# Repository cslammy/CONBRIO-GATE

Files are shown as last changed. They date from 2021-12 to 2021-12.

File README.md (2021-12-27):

# CONBRIO-GATE
Synthesizer module that creates gates that speed up and slow down.
Please see the blog post here for more information:

https://audiodiwhy.blogspot.com/2021/12/con-brio-gate-boards-redesigned-to.html

This is a fix and redesign of the original project you can read about there.
https://audiodiwhy.blogspot.com/2019/04/conbrio-gate-generator-sounds-of-nature.html

Soundcloud demo for this module is here:
https://soundcloud.com/cslamm/con-brio-final

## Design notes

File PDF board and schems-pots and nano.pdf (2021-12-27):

GATEINLED | REVLED | OUTLED | GATEIN
a | FE

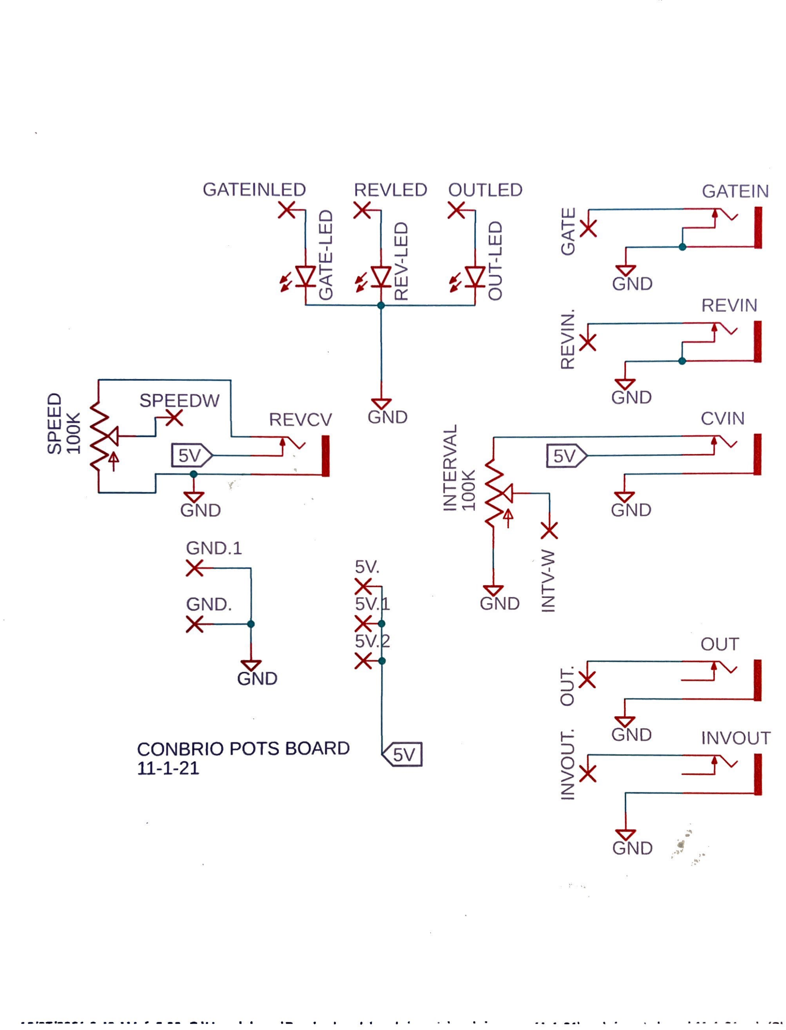
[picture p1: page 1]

<<
oI | O
5 | GND
° | . | REVIN
z
>
Lu
~
a | SPEEDW | GND
aa | <
a
Lu)
FO
ZO
GND.1 | | | 3s
| 5V. | | <
| | | ke
GND | 5V. | GND | Z
| BV.
GND | Ke | EN

Oo

KE | ND
CONBRIO POTS BOARD | 8g | o | NINVOUT 11-1-21 | Of | tC

za

*«
GND # .
c | o | r | o | n | e | n | e we meee eee | meee | se | = | . | . | es | oe | oa | aoe | -s | 8 | moe | ae | se | ee | wwe

## SPEED

## GATE-LED

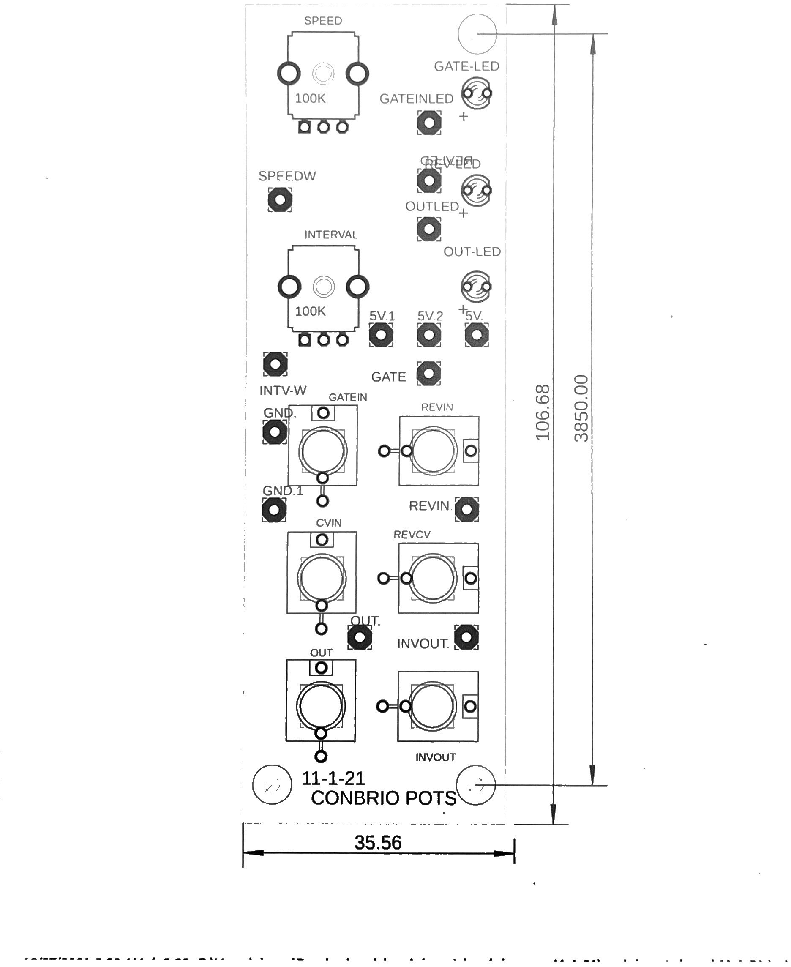
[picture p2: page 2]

# GATEINLED BB

O°

SPEEDW | O68
q
oO | ome
INTERVAL | o
| OUT-LED

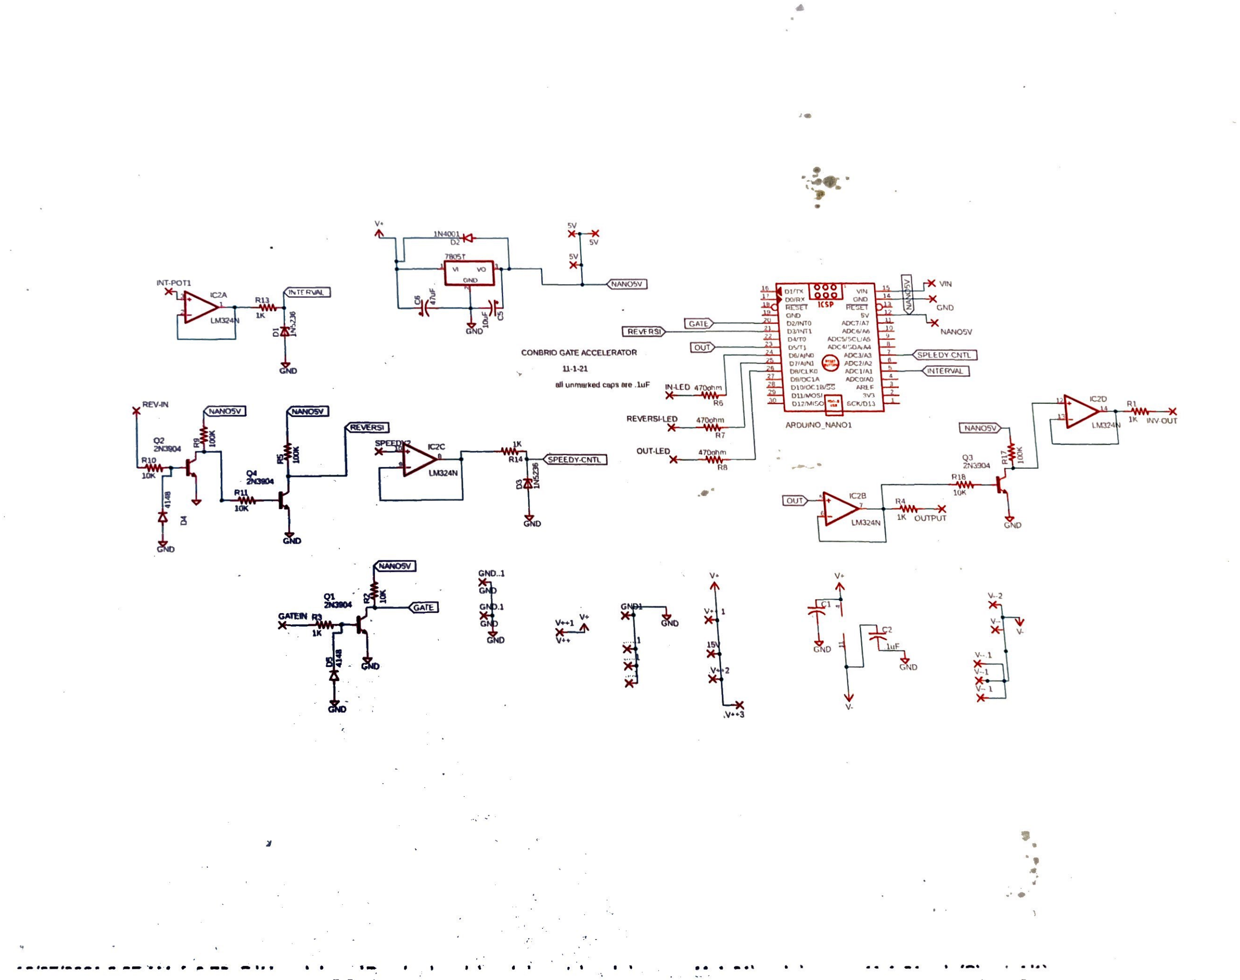
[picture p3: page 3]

so

CONBRIO GATE ACCELERATOR

2-222

oft unmarked caps are uF

¥

weed

7 | ~ | . | .
| | | 9 a ?

?@

? | y
« | -
?
ee | =
?
eetaminaans oom eee | o_o | me | ? | oe | eo | o8 | eos | oo | «wet | eo. | «2 | 2 we | + | ame | + | ates

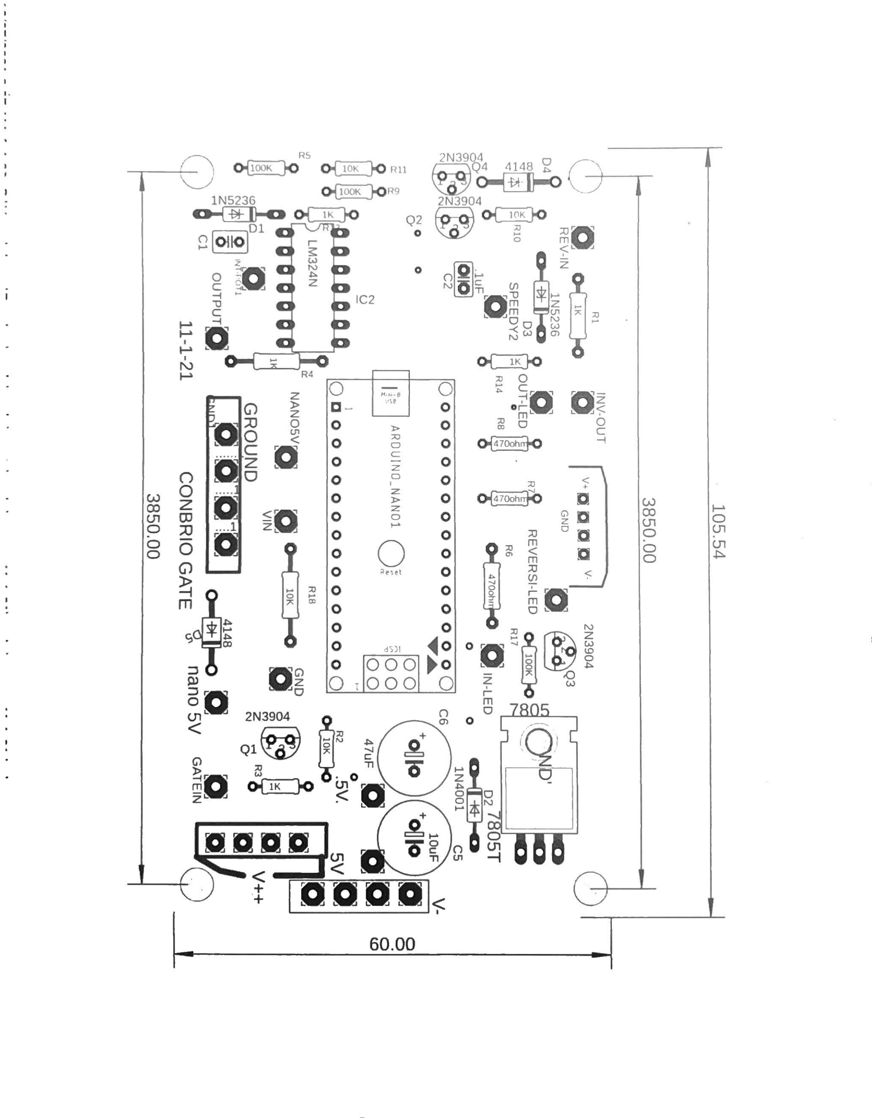
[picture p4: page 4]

105.54 ³⁸⁵⁰.00

Ve a oY²N3904

le el 032 | . RAE©

REVERS!- O00 }O2

# efrw 23] SPEEDY2 Bi?3 -

Ri?

Ar R14RB

230 4am) x{_4700hn] egINLED

## (110) aree 5

4a
c2 OCPCCO0C0D000000000C) cs

## Wa. ¹⁰uF

## -_?ollo 6°

Tszg;

A
47uF om

office a?BV.

4
wa

ourPuT

# Cyba7] 9

11-1-21 CONBRIOGATE nano *

5V_ GATEIN

ome

mee oo?.

v4 eotos eeoe toaa
wees

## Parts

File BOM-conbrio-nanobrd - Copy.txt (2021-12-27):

                                       
7805          7805T  7805T              TO220H       Positive VOLTAGE REGULATOR                                 
ARDUINO_NANO1        ARDUINO_NANO       ARDUINO_NANO Arduino Nano V3.0 Module                                   
C1            .1uF   C-US025-030X050    C025-030X050 CAPACITOR, American symbol                                 
C2            .1uF   C-US025-025X050    C025-025X050 CAPACITOR, American symbol                                 
C5            10uF   CPOL-USE3.5-10     E3,5-10      POLARIZED CAPACITOR, American symbol            C          
C6            47uF   CPOL-USE3.5-10     E3,5-10      POLARIZED CAPACITOR, American symbol            C          
D1            1N5236 ZENER-DIODEDO35Z10 DO35Z10      Z-Diode 5V                                                   
D2            1N4001 1N4148DO35-10      DO35-10      DIODE                                21                    
D3            1N5236 ZENER-DIODEDO35Z10 DO35Z10      Z-Diode 5V                                                   
D4            4148   1N4004             DO41-10      DIODE                                82                    
D5            4148   1N4004             DO41-10      DIODE                                82                    
               
IC2           LM324N LM324N             DIL14        OP AMP   

Note, for IC2, please do not use jfet opamp like TL084. LM324 or LM358 DIP IC is more reliable for this design.
                     
Q1            2N3904 2N3904             TO92         NPN Transistor                                             
Q2            2N3904 2N3904             TO92         NPN Transistor                                             
Q3            2N3904 2N3904             TO92         NPN Transistor                                             
Q4            2N3904 2N3904             TO92         NPN Transistor                                             
R1            1K     R-US_0207/10       0207/10      RESISTOR, American symbol                                  
R2            10K    R-US_0204/7        0204/7       RESISTOR, American symbol                                  
R3            1K     R-US_0204/7        0204/7       RESISTOR, American symbol                                  
R4            1K     R-US_0207/12       0207/12      RESISTOR, American symbol                                  
R5            100K   R-US_0204/7        0204/7       RESISTOR, American symbol                                  
R6            470ohm R-US_0207/10       0207/10      RESISTOR, American symbol                                  
R7            470ohm R-US_0204/7        0204/7       RESISTOR, American symbol                                  
R8            470ohm R-US_0204/7        0204/7       RESISTOR, American symbol                                  
R9            100K   R-US_0204/7        0204/7       RESISTOR, American symbol                                  
R10           10K    R-US_0204/7        0204/7       RESISTOR, American symbol                                  
R11           10K    R-US_0204/7        0204/7       RESISTOR, American symbol                                  
R13           1K     R-US_0204/7        0204/7       RESISTOR, American symbol                                  
R14           1K     R-US_0204/7        0204/7       RESISTOR, American symbol                                  
R17           100K   R-US_0204/7        0204/7       RESISTOR, American symbol                                  
R18           10K    R-US_0207/12       0207/12      RESISTOR, American symbol

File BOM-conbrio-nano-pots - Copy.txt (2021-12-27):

BOM-conbrio-nano-pots  for 11-1-21 design       

CVIN      THONKICONNNEW THONKICONNNEW    WQP-PJ301M-12_JACK 3.5mm socket for Eurorack modular synths                    
INVOUT    THONKICONNNEW THONKICONNNEW    WQP-PJ301M-12_JACK 3.5mm socket for Eurorack modular synths                    
OUT       THONKICONNNEW THONKICONNNEW    WQP-PJ301M-12_JACK 3.5mm socket for Eurorack modular synths 
GATEIN    THONKICONNNEW THONKICONNNEW    WQP-PJ301M-12_JACK 3.5mm socket for Eurorack modular synths      
REVCV     THONKICONNNEW THONKICONNNEW    WQP-PJ301M-12_JACK 3.5mm socket for Eurorack modular synths                    
REVIN     THONKICONNNEW THONKICONNNEW    WQP-PJ301M-12_JACK 3.5mm socket for Eurorack modular synths   
GATE-LED                LED3MM           LED3MM             LED                                               97        
OUT-LED                 LED3MM           LED3MM             LED                                               97        
REV-LED                 LED3MM           LED3MM             LED                                               97                
SPEED     100K          9MM_SNAP-IN_POT_ 9MM_SNAP-IN_POT    9mm vertical snap-in pot, Alpha / Panasonic style      
INTERVAL  100K          9MM_SNAP-IN_POT_ 9MM_SNAP-IN_POT    9mm vertical snap-in pot, Alpha / Panasonic style

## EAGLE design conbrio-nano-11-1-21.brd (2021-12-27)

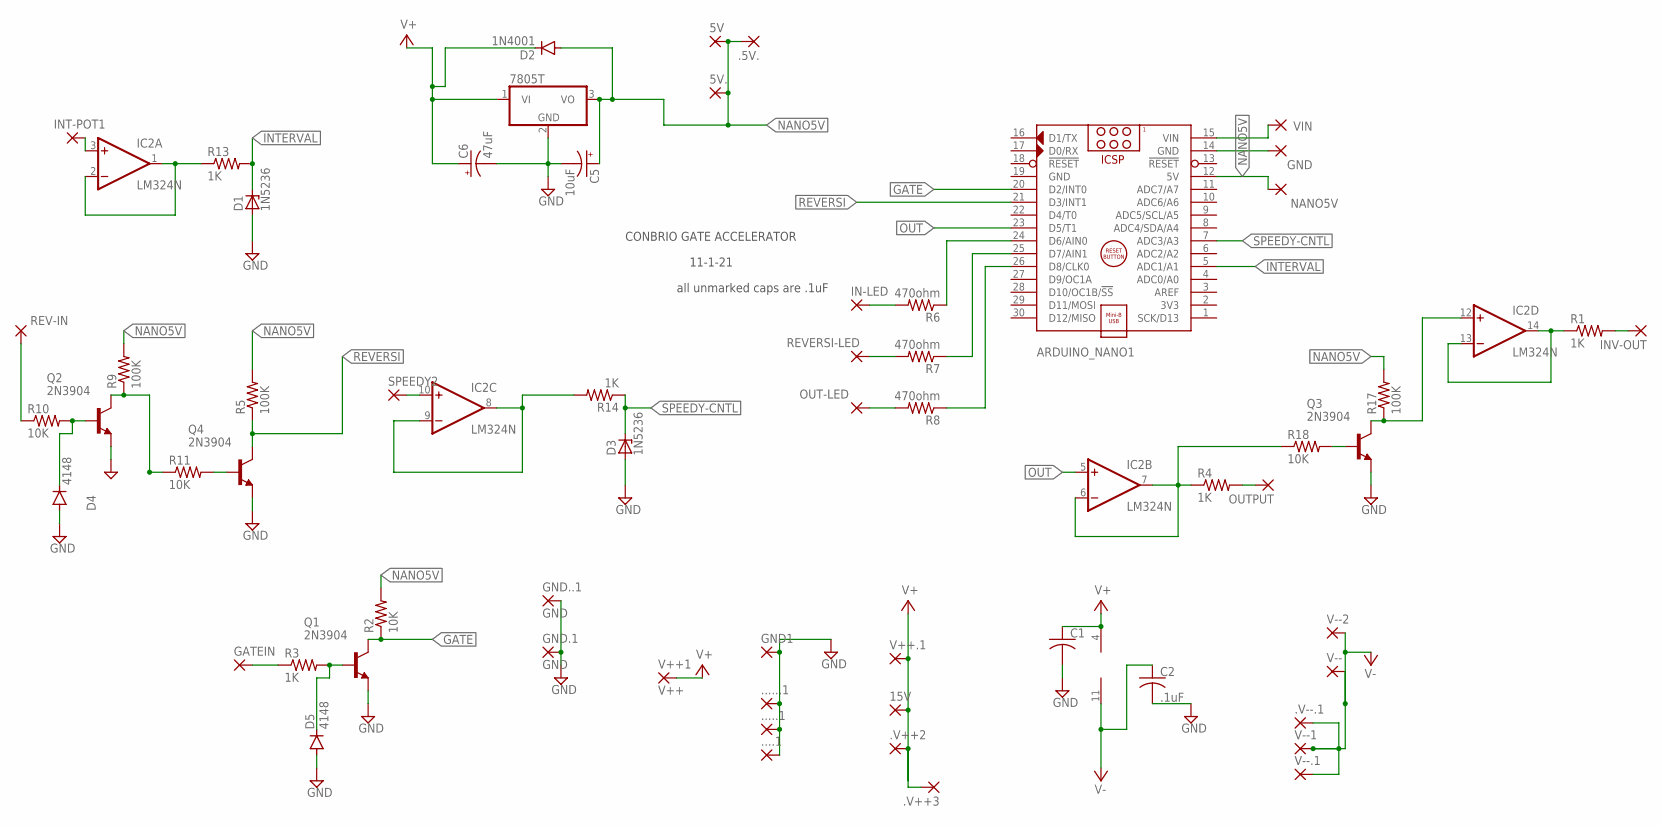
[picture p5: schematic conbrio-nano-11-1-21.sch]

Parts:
5V, .5V.: WIREPAD3,17/1,3; 3,17/1,3
5V.: WIREPAD3,17/1,2; 3,17/1,2
15V, .V++2, .V++3: 2,54/1,0
7805: 7805T; TO220H
....1, .....1, ......1, .V--.1: 3,17/1,3
ARDUINO_NANO1: ARDUINO_NANO
C1: C-US025-030X050; C025-030X050
C2: .1uF; C025-025X050
C5: 10uF; E3,5-10
C6: 47uF; E3,5-10
D1, D3: 1N5236; DO35Z10
D2: 1N4001; DO35-10
D4, D5: 4148; DO41-10
GATEIN: 3,17/1,3
GND, GND1: 3,17/1,3
GND.1, GND..1: GND; 1,6/0,8
IC2: LM324N; DIL14
IN-LED: 3,17/1,3
INT-POT1: 3,17/1,3
INV-OUT: 3,17/1,3
NANO5V: 3,17/1,3
OUT-LED: 3,17/1,3
OUTPUT: 3,17/1,3
Q1, Q2, Q3, Q4: 2N3904; TO92
R1: 1K; 0207/10
R2, R10, R11: 10K; 0204/7
R3, R13, R14: 1K; 0204/7
R4: 1K; 0207/12
R5, R9, R17: 100K; 0204/7
R6: 470ohm; 0207/10
R7, R8: 470ohm; 0204/7
R18: 10K; 0207/12
REV-IN: 3,17/1,3
REVERSI-LED: 3,17/1,3
SPEEDY2: 3,17/1,3
V++1: V++; 1,6/0,8
V++.1: 2,54/1,0
V--: WIREPAD3,17/1,1; 3,17/1,1
V--1, V--.1: 3,17/1,3
V--2: WIREPAD1,6/0,8; 1,6/0,8
VIN: 3,17/1,3

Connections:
GATE: ARDUINO_NANO1.20 (D2/INT0), Q1.1 (C), R2.1
GND: 7805.2 (GND), ....1.1, .....1.1, ......1.1, ARDUINO_NANO1.19 (GND), C1.2, C2.2, C5.-, C6.-, D1.A, D3.A, D4.A, D5.A, GND1.1, GND.1.1, GND..1.1, Q1.3 (E), Q2.3 (E), Q3.3 (E), Q4.3 (E)
INTERVAL: ARDUINO_NANO1.5 (ADC1/A1), D1.C, R13.2
INVOUT: IC2.13 (-IN), IC2.14 (OUT), R1.1
unnamed: GATEIN.1, R3.1
unnamed: D5.C, Q1.2 (B), R3.2
unnamed: INV-OUT.1, R1.2
unnamed: Q2.1 (C), R9.1, R11.1
unnamed: OUTPUT.1, R4.2
unnamed: IC2.3 (+IN), INT-POT1.1
unnamed: Q4.2 (B), R11.2
unnamed: IC2.6 (-IN), IC2.7 (OUT), R4.1, R18.1
unnamed: R10.1, REV-IN.1
unnamed: IN-LED.1, R6.2
unnamed: ARDUINO_NANO1.24 (D6/AIN0), R6.1
unnamed: R7.2, REVERSI-LED.1
unnamed: ARDUINO_NANO1.25 (D7/AIN1), R7.1
unnamed: OUT-LED.1, R8.2
unnamed: ARDUINO_NANO1.26 (D8/CLK0), R8.1
unnamed: IC2.12 (+IN), Q3.1 (C), R17.1
unnamed: IC2.10 (+IN), SPEEDY2.1
unnamed: D4.C, Q2.2 (B), R10.2
unnamed: IC2.1 (OUT), IC2.2 (-IN), R13.1
unnamed: Q3.2 (B), R18.2
unnamed: ARDUINO_NANO1.15 (VIN), VIN.1
unnamed: ARDUINO_NANO1.14 (GND), GND.1
NANO5V: 5V.1, 5V..1, 7805.3 (VO), .5V..1, ARDUINO_NANO1.12 (5V), C5.+, D2.A, NANO5V.1, R2.2, R5.2, R9.2, R17.2
OUT: ARDUINO_NANO1.23 (D5/T1), IC2.5 (+IN)
REVERSI: ARDUINO_NANO1.21 (D3/INT1), Q4.1 (C), R5.1
SPEEDY: IC2.8 (OUT), IC2.9 (-IN), R14.2
SPEEDY-CNTL: ARDUINO_NANO1.7 (ADC3/A3), D3.C, R14.1
V+: 15V.1, 7805.1 (VI), .V++2.1, .V++3.1, C1.1, C6.+, D2.C, IC2.4 (V+), V++1.1, V++.1.1
V-: .V--.1.1, C2.1, IC2.11 (V-), V--.1, V--1.1, V--2.1, V--.1.1

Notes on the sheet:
CONBRIO GATE ACCELERATOR
11-1-21
all unmarked caps are .1uF

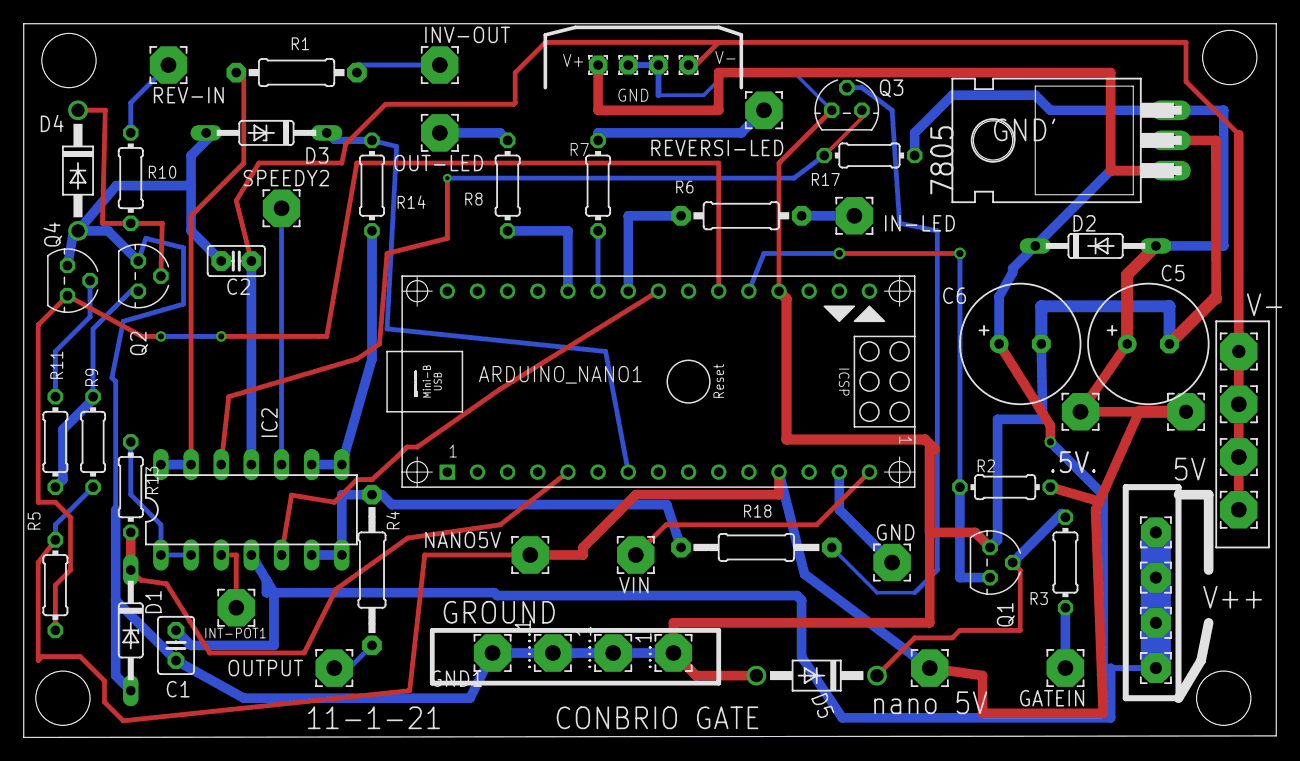
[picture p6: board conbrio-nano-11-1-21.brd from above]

Board: 2 copper layers, 105.5 x 60.1 mm, 62 parts (0 on the bottom side), 33 nets.

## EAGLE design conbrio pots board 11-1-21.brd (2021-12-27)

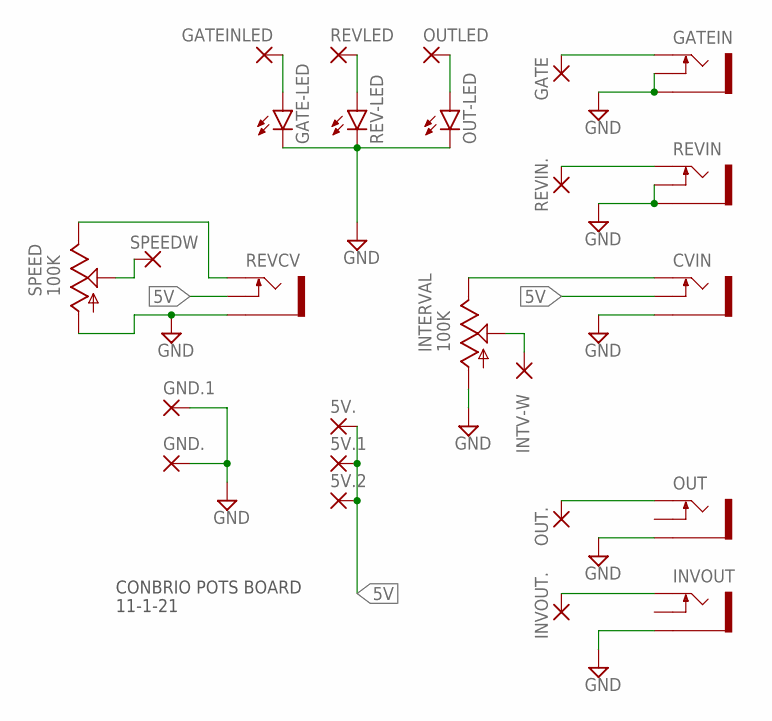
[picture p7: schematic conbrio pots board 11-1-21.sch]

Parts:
5V., 5V.1, 5V.2: WIREPAD3,17/1,3; 3,17/1,3
CVIN: THONKICONNNEW; WQP-PJ301M-12_JACK
GATE: WIREPAD3,17/1,3; 3,17/1,3
GATE-LED: LED3MM
GATEIN: THONKICONNNEW; WQP-PJ301M-12_JACK
GATEINLED: WIREPAD3,17/1,3; 3,17/1,3
GND., GND.1: WIREPAD3,17/1,3; 3,17/1,3
INTERVAL: 100K; 9MM_SNAP-IN_POT
INTV-W: WIREPAD3,17/1,3; 3,17/1,3
INVOUT: THONKICONNNEW; WQP-PJ301M-12_JACK
INVOUT.: WIREPAD3,17/1,3; 3,17/1,3
OUT: THONKICONNNEW; WQP-PJ301M-12_JACK
OUT-LED: LED3MM
OUT.: WIREPAD3,17/1,3; 3,17/1,3
OUTLED: WIREPAD3,17/1,3; 3,17/1,3
REV-LED: LED3MM
REVCV: THONKICONNNEW; WQP-PJ301M-12_JACK
REVIN: THONKICONNNEW; WQP-PJ301M-12_JACK
REVIN.: WIREPAD3,17/1,3; 3,17/1,3
REVLED: WIREPAD3,17/1,3; 3,17/1,3
SPEED: 100K; 9MM_SNAP-IN_POT
SPEEDW: WIREPAD3,17/1,3; 3,17/1,3

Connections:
5V: 5V..1, 5V.1.1, 5V.2.1, CVIN.P$2_SWITCH (SWITCH), REVCV.P$2_SWITCH (SWITCH)
GND: CVIN.P$3_SLEEVE (SLEEVE), GATE-LED.K (C), GATEIN.P$2_SWITCH (SWITCH), GATEIN.P$3_SLEEVE (SLEEVE), GND..1, GND.1.1, INTERVAL.1 (A), INVOUT.P$3_SLEEVE (SLEEVE), OUT.P$3_SLEEVE (SLEEVE), OUT-LED.K (C), REV-LED.K (C), REVCV.P$3_SLEEVE (SLEEVE), REVIN.P$2_SWITCH (SWITCH), REVIN.P$3_SLEEVE (SLEEVE), SPEED.1 (A)
unnamed: GATE-LED.A, GATEINLED.1
unnamed: REV-LED.A, REVLED.1
unnamed: OUT-LED.A, OUTLED.1
unnamed: CVIN.P$1_TIP (TIP), INTERVAL.3 (E)
unnamed: INTERVAL.2 (S), INTV-W.1
unnamed: REVCV.P$1_TIP (TIP), SPEED.3 (E)
unnamed: SPEED.2 (S), SPEEDW.1
unnamed: GATE.1, GATEIN.P$1_TIP (TIP)
unnamed: REVIN.P$1_TIP (TIP), REVIN..1
unnamed: OUT.P$1_TIP (TIP), OUT..1
unnamed: INVOUT.P$1_TIP (TIP), INVOUT..1

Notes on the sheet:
CONBRIO POTS BOARD
11-1-21

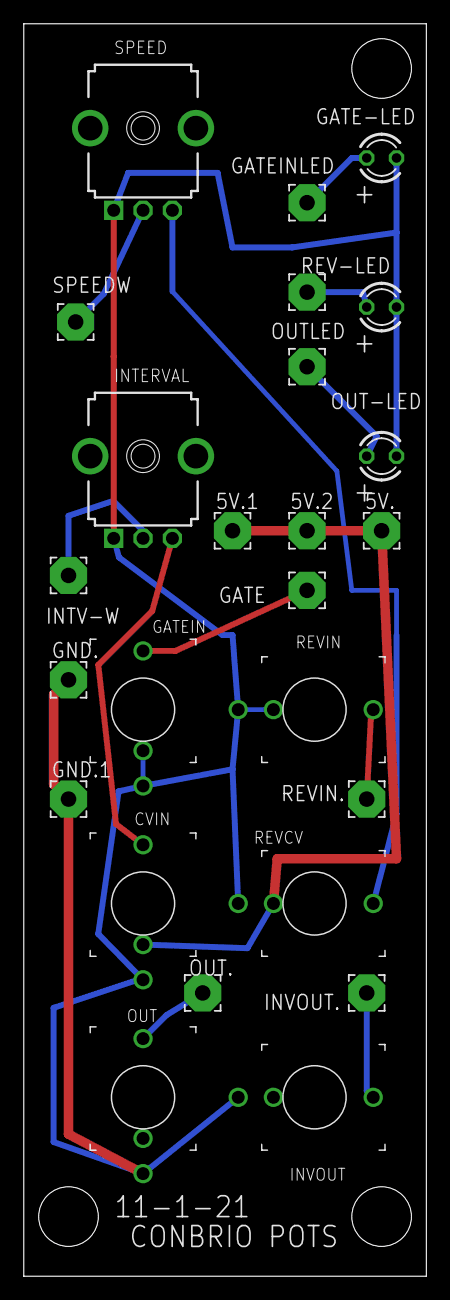
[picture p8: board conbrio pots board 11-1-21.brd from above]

Board: 2 copper layers, 34.3 x 106.7 mm, 25 parts (0 on the bottom side), 13 nets.

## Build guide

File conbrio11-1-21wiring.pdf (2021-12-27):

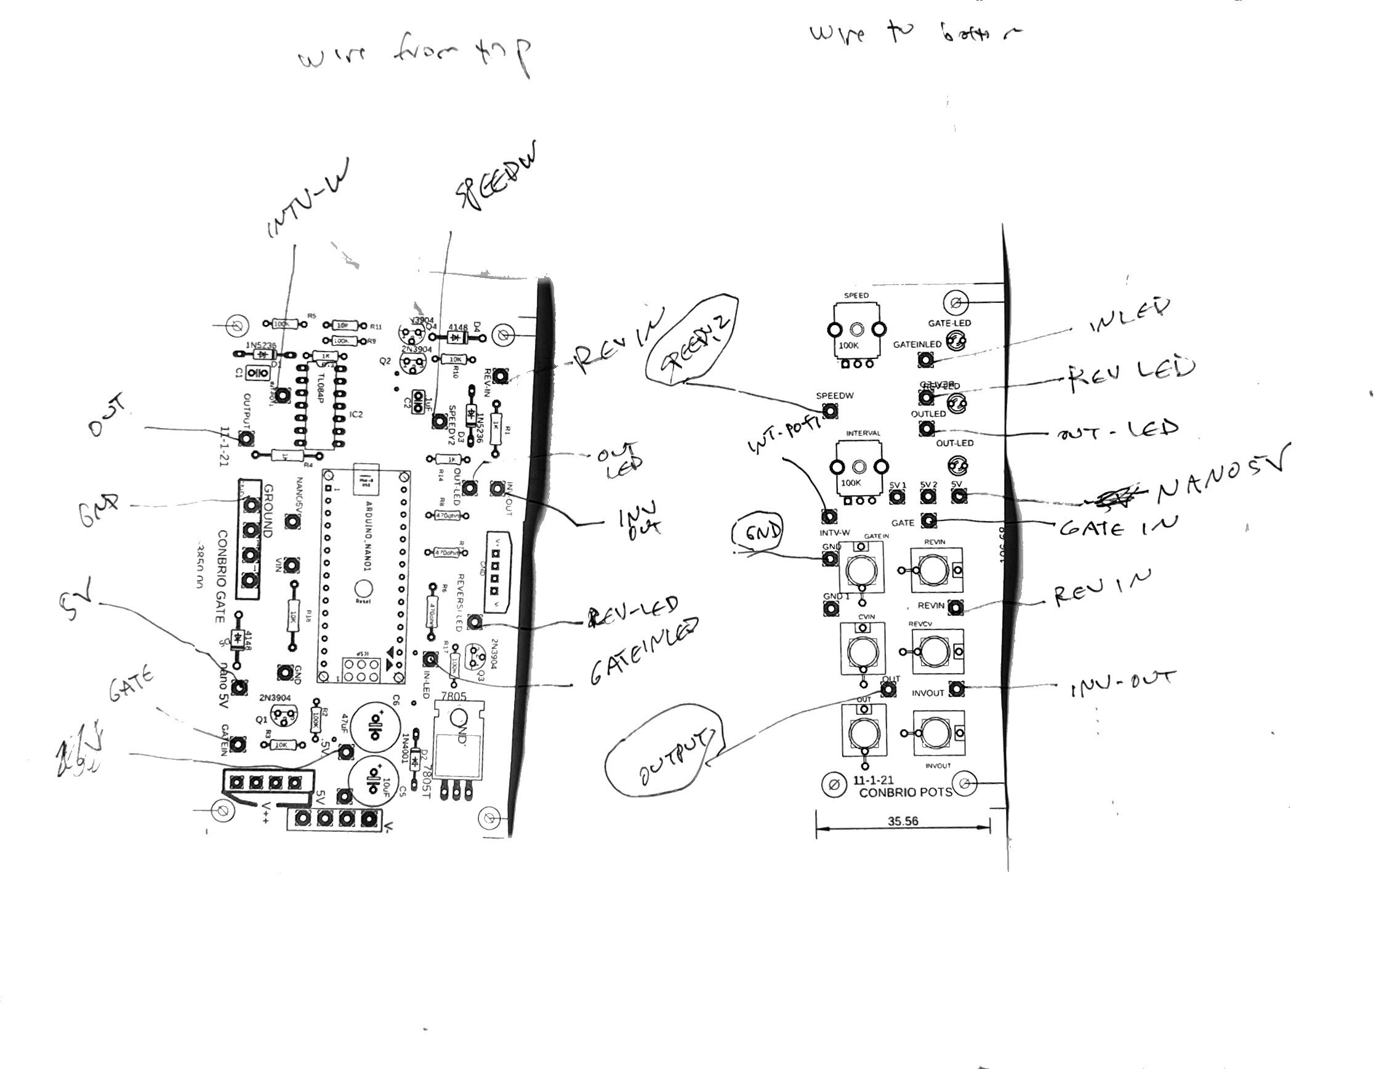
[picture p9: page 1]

Wy | WY | howe
5 | 0 | 4

SPEEOW

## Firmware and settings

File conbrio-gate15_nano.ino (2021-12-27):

//loaded 11-12-18 6:12PM

//attiny interrupt test
//https://thewanderingengineer.com/2014/08/11/pin-change-interrupts-on-attiny85/

//version 3 basic idea
//version 4 fixed interrupt so it works like a gate
//version 5 get random shit going
//version 6 control interval w' pot
//version 7 cleaned up interrupt gate and general fixes.
//version 8 got most of Attiny going but ran out of pins
//version 9 ported to nano (more pins!)
//version 13 got rid of interrupts, changed gate logic, tweaked pot values.
//version 14 added LED I/O, set delays
//version 15 switched reversi logic (buffer no longer inverts--new hardware)

#define F_CPU 1000000UL
#include <avr/io.h>
#include <util/delay.h>
#include <avr/interrupt.h>



const byte blink=13; // built in LED port on nano
boolean gateon = LOW; // logic used for gated elements LOW or HIGH
int x = 0;
int a = 0;
int b = 0;
int c = 0;
int d = 0;
int e = 0;

float upwards = 0;
long randomnumber = 0;
//int printme = 0;
int headsortails = 0;
int interval = 0;  //how long for initial interval read
int interval2 = 0; // use this to control blinking
int speedy = 0; // length between blinks
boolean reverski=HIGH; // do we go fast to slow or slow to fast?
int randomvalue = 15;  // add musicality to your dukey.
int xx = 1;
void setup()
{
    Serial.begin( 9600 );
   
// interrupt on for Nano
  


  pinMode(A1, INPUT); // interval 0 - 300
  pinMode(A3, INPUT); // speedy.  distance between each pulse.
  pinMode(3, INPUT); //reverski.  fast to slow or slow to fast
  pinMode(2, INPUT); // gate in used as INT0
  pinMode(8, OUTPUT); //LED for gate output 
  pinMode(6, OUTPUT); // LED for gate input
  pinMode(7, OUTPUT); // LED for reverski status
  pinMode(blink, OUTPUT); // internal LED on Nano

  
 // attachInterrupt(digitalPinToInterrupt(3), myisr2, HIGH); // reverski signal 
//  attachInterrupt(digitalPinToInterrupt(2), myisr, HIGH); // get gate signal; LOW is TRUE 
}


//"waitaround" lets you avoid delay() stupidity.  220 is about 1 second on a 1Mhz ATTINY85
void waitaround (int x)
{
 for (a = 0;a < x;a++)
  waitaround3(x);
}

void waitaround2 (int x)


{
 for (b = 0;b < x;b++)
 x = x;
}

void waitaround3 (int x)
{
  for (c = 0;c < x;c++)
  waitaround2(x);
}





void loop()

{
delay(10);
reverski = digitalRead(3);
gateon = digitalRead(2);
//Serial.println(reverski);  

//this is getslower routine.

if (reverski == LOW)
    {
      
    digitalWrite(7,LOW); // turn LED **OFF** which means we are in get slower mode
    
    if (xx == 0)
    {
    interval = (analogRead(A1));
    xx = 1;
    }
    //Serial.println("reverski is:");
    //Serial.println(reverski);
       if (gateon==LOW)
       {
         digitalWrite(6,HIGH); // turn on gate in status LED
   //    Serial.println("gateon in getslowweris:");

     //  Serial.println("gateon upwards = interval; is true in getslower loop");
 
   

 /*      Serial.print("interval:");      
       Serial.println(interval);
       Serial.print("speedy is:");
       Serial.println(speedy);

  */      
   
 
        
        headsortails = random(1,2);
        
        randomnumber = random(randomvalue);   
       
         digitalWrite(blink,HIGH);
         digitalWrite(8,HIGH); // lite LED that gate out is on
         digitalWrite(5,HIGH); // Send 5V to output buffer
         
         waitaround(interval* .5);
         digitalWrite(blink,LOW);
         digitalWrite(8,LOW); // un-lite LED that gate out is on
         digitalWrite(5,LOW); // Send GND to output buffer     
                  
                  waitaround(interval* .5);


          speedy = (analogRead(A3)/5);
       
          if (headsortails == 1)
           {
           interval = interval + speedy + randomnumber; 
           }
          else
           {
           interval = interval + speedy;
           }


         } 
         if (gateon==HIGH)
         {
          digitalWrite(blink,LOW);
          digitalWrite(6, LOW); // turn off input status LED
          xx = 0;    
         }

      
   }  // end if reverski


//THIS IS THE GET FASTER ROUTINE.

if (reverski == HIGH)
    {
         digitalWrite(7, HIGH);  // turn reverski LED **ON** which means we are get faster mode.
         
         delay(10);
         if (xx == 1)
            {
              interval2 = (analogRead(A1));             
            }       
         if (gateon==LOW)
            { 
             digitalWrite(6,HIGH); // turn on gate input status LED 
            xx = 0; // don't get a new read for interval2   
 //         Serial.println("gateon is LOW in get faster loop");
         
            headsortails = random(1,2);
            randomnumber = random(randomvalue);   
            waitaround(interval2);   
            digitalWrite(blink,HIGH);
            digitalWrite(8,HIGH); // lite LED that gate out is on
            digitalWrite(5,HIGH); // Send 5V to output buffer
            
            waitaround(interval2);
            digitalWrite(blink,LOW);
                   
            digitalWrite(8,LOW); // un-lite LED that gate out is on
            digitalWrite(5,LOW); // Send gnd to output buffer
            speedy = (analogRead(A3)/20);

            

            
            if (headsortails == 1)
            
                            
                {
                interval2 = interval2 - (speedy-randomnumber);
                }

           
                              
              else
                {
                interval2 = interval2 - (speedy + randomnumber);
                }

               if (interval2 < 5)
               {
                interval2 = 70;
               }
        
              
        } // end while gateon == LOW
        if (gateon==HIGH)
        {
          digitalWrite(blink,LOW);
          digitalWrite(6,LOW); // turn off gate input status LED
          
          xx = 1;
          speedy = 0;
        } // end gateon = high
    } // END IF REVERSKI HIGH

} // end loop ()

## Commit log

2021-12-27 PDF of schems and boards for this module
2021-12-27 Initial upload
    Gerbers for pots and main "nano" board
2021-12-27 Initial Upload
    BOM for project
2021-12-27 Add files via upload
    Arduino sketch INO file for Arduino Nano for this project.
2021-12-27 Add files via upload
    Eagle SCH (schematic) and BRD (Board) files for this module
    [conbrio pots board 11-1-21.brd, conbrio pots board 11-1-21.sch, conbrio-nano-11-1-21.brd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]
2021-12-27 Add files via upload
    PDF for schematics and Boards for this project.
2021-12-27 Add files via upload
    Wiring between POTS and NANO board for this project
